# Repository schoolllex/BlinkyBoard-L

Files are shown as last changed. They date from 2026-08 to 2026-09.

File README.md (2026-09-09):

**BlinkyBoard-L**
PCB Card follow the tutorial and little decoration for not expensive components

## Overview
Features:
- Beautiful
- Personnalized
- Works
- Not expensive

## Hardware
BOM at the end of file and in REPO
[Gerber](/555led/)
[Kicad schm](/555led/)
[Kicad pcb](/555led/)





## Inspo

This project was inspired by a Hack Club tutorial about making a PCB using a 555 timer and a decade counter.

I thought it would be a fun little project to follow the tutorial, while adding my own PCB design and a small personalized decoration.

The goal was to keep the project simple, cheap and fun, while still creating a real PCB that I could manufacture and assemble myself.

The original tutorial did not provide a complete BOM, so I had to find and select the components myself, mainly using AliExpress.

## BOM

Here is the BOM:
| # | Composant | Prix (€) | Prix ($) | Lien |
| --- | --- | --- | --- | --- |
| 1 | PCB | 3,00 € | $3,48 | - |
| 2 | Rubycon 50YXF1MEFC5X11 | 0,54 € | $0,63 | [Lien](https://www.lcsc.com/product-detail/C2927584.html) |
| 3 | CL05B103KB5NNNC | 0,59 € | $0,68 | [Lien](https://www.lcsc.com/product-detail/C15195.html) |
| 4 | TJ-L3FYTGHKMCGSFLC7K-A5 | 0,59 € | $0,68 | [Lien](https://www.lcsc.com/product-detail/C330747.html) |
| 5 | C5305 | 0,50 € | $0,58 | [Lien](https://www.lcsc.com/product-detail/C5305.html) |
| 6 | C52016392 | 0,65 € | $0,75 | [Lien](https://www.lcsc.com/product-detail/C52016392.html) |
| 7 | ST-4ETG 1K OHM (102) | 0,79 € | $0,92 | [Lien](https://www.lcsc.com/product-detail/C132881.html) |
| 8 | MFR-25FTE52-470R | 0,90 € | $1,04 | [Lien](https://www.lcsc.com/product-detail/C173020.html) |
| 9 | T93YA503KT20 | 3,43 € | $3,98 | [Lien](https://www.lcsc.com/product-detail/C7061697.html) |
| 10 | NE555P | 1,35 € | $1,57 | [Lien](https://www.lcsc.com/product-detail/C46749.html) |
| 11 | CD4017BED | 0,60 € | $0,70 | [Lien](https://www.lcsc.com/product-detail/C51898328.html) |
|  | **Total des composants listés** | **12,94 €** | **$15,01** |  |
|  | **Total annoncé** | **12,94 €** | **$15,01** |  |

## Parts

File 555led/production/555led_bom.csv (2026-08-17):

Designator | Footprint | Quantity | Value | LCSC Part #
C1 | CP_Radial_D5.0mm_P2.00mm | 1 | 1uF
C2 | C_Disc_D7.5mm_W2.5mm_P5.00mm | 1 | 0.01uF
D1, D10, D2, D3, D4, D5, D6, D7, D8, D9 | LED_D3.0mm | 10 | LED
J1 | PinHeader_1x02_P2.54mm_Vertical | 1 | Conn_01x02_Socket
J2 | PinHeader_1x01_P2.54mm_Vertical | 1 | Conn_01x01_Socket
R1 | R_Axial_DIN0207_L6.3mm_D2.5mm_P7.62mm_Horizontal | 1 | 1K
R2 | R_Axial_DIN0207_L6.3mm_D2.5mm_P7.62mm_Horizontal | 1 | 470R
RV1 | Potentiometer_Vishay_T93YA_Vertical | 1 | 50K
U1 | DIP-8_W7.62mm | 1 | NE555P
U2 | N16 | 1 | 4017

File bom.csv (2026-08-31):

Reference | Component | Price_EUR | Price_USD | Link
1 | PCB | 3.00 | 3.48
2 | Rubycon 50YXF1MEFC5X11 | 0.54 | 0.63 | https://www.lcsc.com/product-detail/C2927584.html
3 | CL05B103KB5NNNC | 0.59 | 0.68 | https://www.lcsc.com/product-detail/C15195.html
4 | TJ-L3FYTGHKMCGSFLC7K-A5 | 0.59 | 0.68 | https://www.lcsc.com/product-detail/C330747.html
5 | C5305 | 0.50 | 0.58 | https://www.lcsc.com/product-detail/C5305.html
6 | C52016392 | 0.65 | 0.75 | https://www.lcsc.com/product-detail/C52016392.html
7 | ST-4ETG 1K OHM (102) | 0.79 | 0.92 | https://www.lcsc.com/product-detail/C132881.html
8 | MFR-25FTE52-470R | 0.90 | 1.04 | https://www.lcsc.com/product-detail/C173020.html
9 | T93YA503KT20 | 3.43 | 3.98 | https://www.lcsc.com/product-detail/C7061697.html
10 | NE555P | 1.35 | 1.57 | https://www.lcsc.com/product-detail/C46749.html
11 | CD4017BED | 0.60 | 0.70 | https://www.lcsc.com/product-detail/C51898328.html

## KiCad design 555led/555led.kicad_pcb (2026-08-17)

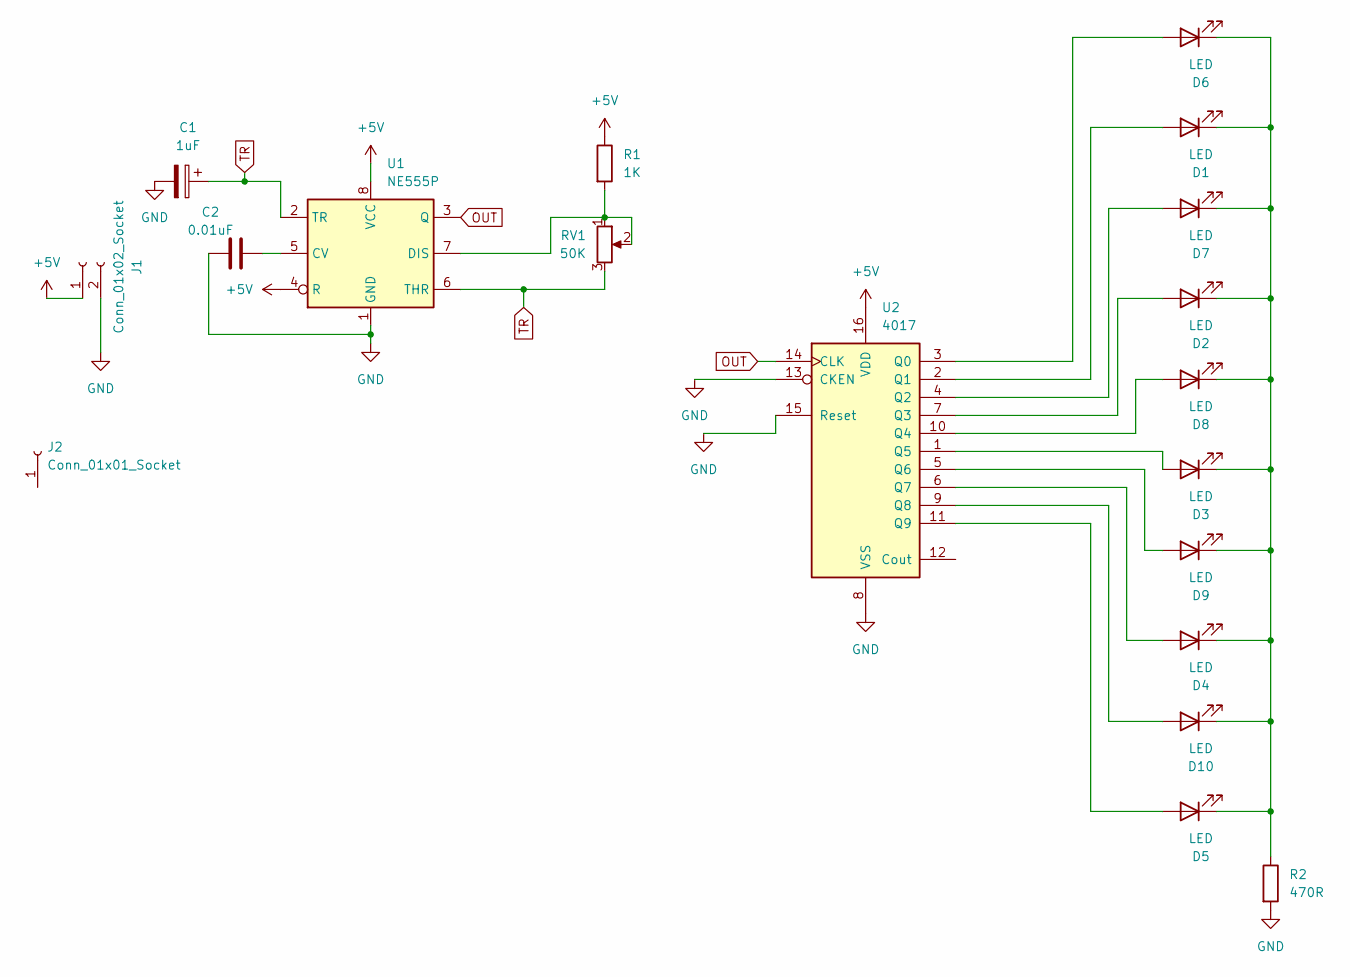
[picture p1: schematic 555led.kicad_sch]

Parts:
C1: 1uF; CP_Radial_D5.0mm_P2.00mm
C2: 0.01uF; C_Disc_D7.5mm_W2.5mm_P5.00mm
D1, D2, D3, D4, D5, D6, D7, D8, D9, D10: LED; LED_D3.0mm
J1: Conn_01x02_Socket; PinHeader_1x02_P2.54mm_Vertical
J2: Conn_01x01_Socket; PinHeader_1x01_P2.54mm_Vertical
R1: 1K; R_Axial_DIN0207_L6.3mm_D2.5mm_P7.62mm_Horizontal
R2: 470R; R_Axial_DIN0207_L6.3mm_D2.5mm_P7.62mm_Horizontal
RV1: 50K; Potentiometer_Vishay_T93YA_Vertical
U1: NE555P; DIP-8_W7.62mm
U2: 4017; N16

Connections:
+5V: J1.1, R1.1, U1.4 (R), U1.8 (VCC), U2.16 (VDD)
GND: C1.2, C2.1, J1.2, R2.2, U1.1 (GND), U2.8 (VSS), U2.13 (CKEN), U2.15 (Reset)
unnamed: D1.2 (A), U2.2 (Q1)
unnamed: D1.1 (K), D2.1 (K), D3.1 (K), D4.1 (K), D5.1 (K), D6.1 (K), D7.1 (K), D8.1 (K), D9.1 (K), D10.1 (K), R2.1
unnamed: D2.2 (A), U2.7 (Q3)
unnamed: D3.2 (A), U2.1 (Q5)
unnamed: D4.2 (A), U2.6 (Q7)
unnamed: D5.2 (A), U2.11 (Q9)
unnamed: D6.2 (A), U2.3 (Q0)
unnamed: D7.2 (A), U2.4 (Q2)
unnamed: D8.2 (A), U2.10 (Q4)
unnamed: D9.2 (A), U2.5 (Q6)
unnamed: D10.2 (A), U2.9 (Q8)
unnamed: C2.2, U1.5 (CV)
unnamed: R1.2, RV1.1, RV1.2, U1.7 (DIS)
OUT: U1.3 (Q), U2.14 (CLK)
TR: C1.1, RV1.3, U1.2 (TR), U1.6 (THR)

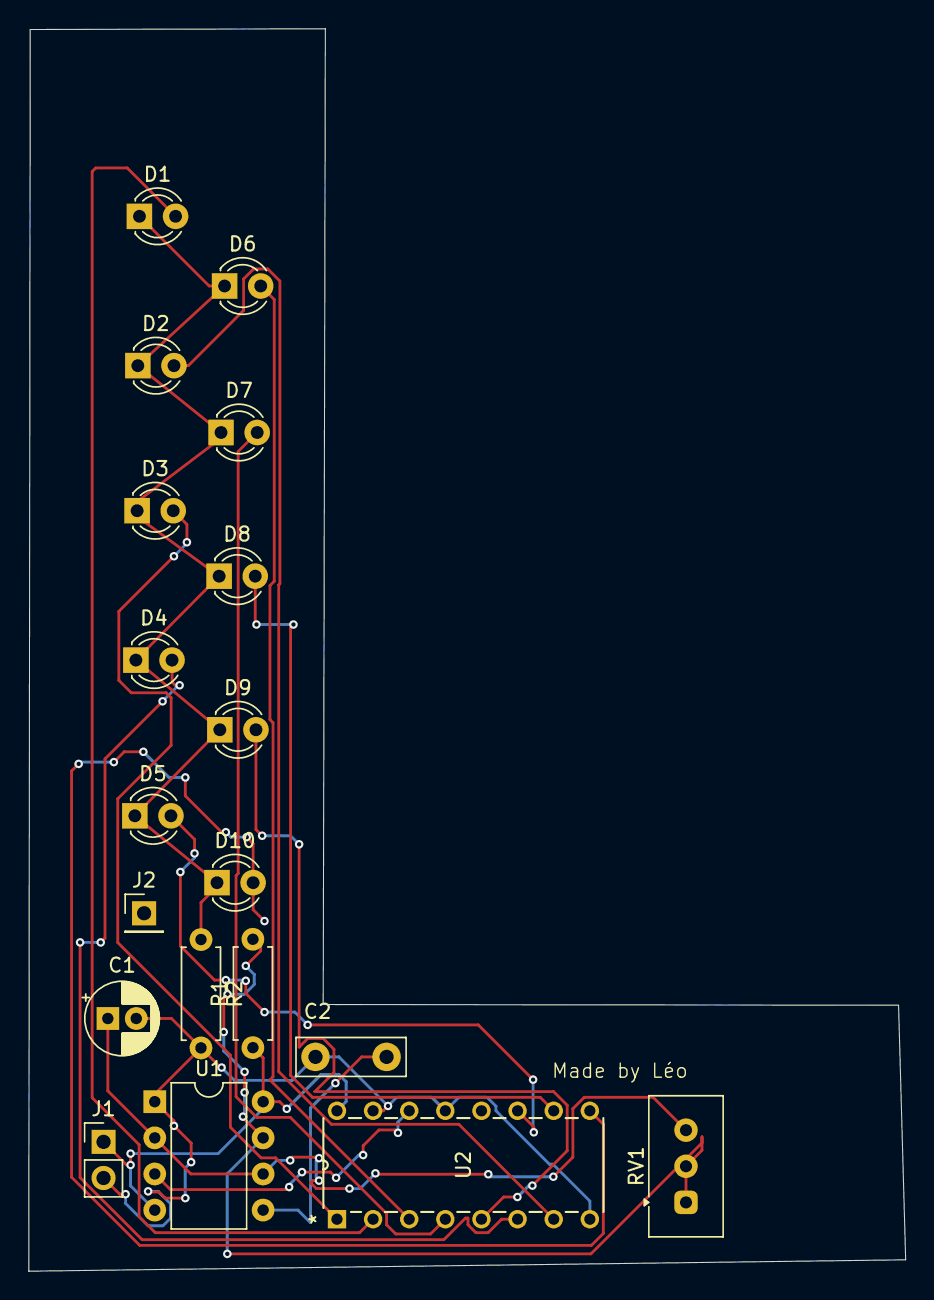
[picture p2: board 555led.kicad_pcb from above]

Board: 2 copper layers, 61.6 x 87.3 mm, 19 parts (0 on the bottom side), 17 nets.

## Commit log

2026-08-31 Revise BOM with updated components and prices
    Updated the BOM with new component details and adjusted prices.
2026-08-31 Revise bom.csv with new component details
    Updated the bill of materials with new components and pricing.
    [bom.csv]
2026-08-31 Enhance README with project inspiration and BOM
    Added project inspiration and BOM details to README.
